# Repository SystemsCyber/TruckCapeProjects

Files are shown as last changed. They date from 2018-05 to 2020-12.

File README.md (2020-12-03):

# TruckCapeProjects
Projects teaching the basics of using the TruckDuck or Truck Cape on a Beagle Bone Black with Python.

Checkout the Jupyter directory for Python code embedded in a Juptyer notebook. To start a jupyter server on the Beagle Bone, use this command:

```
jupyter notebook --ip 192.168.7.2 --no-browser
```

Note: this is not secure, so only use this on a local network or USB connection.

## Getting Started
Login to your beaglebone and run the following command to copy this repository into your directory:

```
git clone https://github.com/SystemsCyber/TruckCapeProjects.git
```

Once this is copied in, you can update the repository by changing directory into the repostory and running ```git pull```

## Hardware
See the docs directory for details. You can buy the board directly from OSHPark and source the parts from Digikey or Mouser. 

## Linux
The Linux image to run on the BeagleBone's eMMC can be downloaded, decompressed, imaged to an SD card. When the BeagleBone Black boots from the SD card, it will burn the eMMC to have the necessary contents to run the exercises in this repository. 

For the impatient, here is a link to the most current image based on the modifications:

[TruckCapeImage-2020-11-14_4.19.img.xz](https://www.engr.colostate.edu/~jdaily/files/TruckCapeImage-2020-11-14_4.19.img.xz)

This image was built based on the guidance in [OSBuildInstructions.md](OSBuildInstructions.md).

## Getting Started
### Windows Software
If this is your first time with a Heavy Truck Cape with BeagleBoneBlack, then you'll need some software on your computer to interface with it. This readme assumes you are using Windows. Linux and Mac have shell utilities built-in already. For Windows users, you'll need the following:
1. PuTTy
2. WinSCP 

### Logging In
1. Plug in the a Mini USB cable between the BeagleBone and your computer
2. Give the system some time to boot
2. Open PuTTy
3. Specify the Host Name (or IP address) as 192.168.7.2
4. Press Open
5. Use the following credentials:

Default Credentials
U: debian P: temppwd
Please change the password if this is connected to the Internet.

### Logging Out or Shutting Down
The system may shut down if the +12V feed is removed, even if the USB or 5V power jack is connected. Be sure to shut down the Linux system before unplugging the device. 

```
sudo shutdown -h now
```

### Change the Baud Rate
To figure out the bitrate of the devices, issue the following command
```
ip -details -statistics link show can1
```
which gives output like the following showing a bitrate of 250000 bps.
```
can1: <NOARP,UP,LOWER_UP,ECHO> mtu 16 qdisc pfifo_fast state UNKNOWN mode DEFAULT qlen 10
    link/can
    can state ERROR-PASSIVE (berr-counter tx 0 rx 127) restart-ms 0
    bitrate 250000 sample-point 0.875
    tq 250 prop-seg 6 phase-seg1 7 phase-seg2 2 sjw 1
    c_can: tseg1 2..16 tseg2 1..8 sjw 1..4 brp 1..1024 brp-inc 1
    clock 24000000
    re-started bus-errors arbit-lost error-warn error-pass bus-off
    0          0          0          123        25203      0
    RX: bytes  packets  errors  dropped overrun mcast
    2611059    336058   0       0       0       0
    TX: bytes  packets  errors  dropped carrier collsns
    0          0        0       0       0       0
```

Enter the following commmands to change the CAN bitrate to 666000 on the CAN0 channel.
CAN0 on SocketCAN is the CAN2 channel on the J1939 connector.
```
sudo ip link set can0 down
sudo ip link set can0 type can bitrate 666666
sudo ip link set can0 up
```
The resulting terminal should display something like this if CAN0 is connected to a 666k CAN network.
```
candump can0
  can0  10EBFF3D   [8]  01 00 00 00 00 00 00 00
  can0  10EBFF3D   [8]  01 00 00 00 00 00 00 00
  can0  10EBFF3D   [8]  01 00 00 00 00 00 00 00
  can0  08FE6E0B   [8]  FF FF FF FF FF FF FF FF
  can0  14FEAE17   [8]  FF FF FF FF FF FF FF FF
  can0  08FF0400   [8]  01 00 00 00 A8 61 4D 12
  can0  08FF0400   [8]  01 00 00 00 A8 61 6D 76
  can0  10EBFF3D   [8]  01 00 00 00 00 00 00 00
  can0  08FF0400   [8]  01 00 00 00 A8 61 4D 12
```

A similar strategy will be used for CAN1 and other bit rates.

## Challenge Ideas
### Log all data to an SD Card
Adapt the startup script to log all data from the J1939 (CAN1), CAN0, and Both J1708 channels to log to files on a large SD card installed in the BeagleBone card slot.

### Automatic RTC
Add the ability to set the time using the an I2C based Real Time Clock chip. Normal operation relies on a network connection to get time.

### Send and Receive CAN messages over UDP
Build a network bridge for CAN and Ethernet. 

### Build a can-utils website
Host a website on the Beaglebone to interface with SocketCAN

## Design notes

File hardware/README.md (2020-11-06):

# TruckCape for the Beagle Bone Black

This directory has Altium schematics, printed circuit boards, and PCB project files.

All components are through hole, so it is easy to build with just a soldering iron.

PDFs of the schematics are available. The board in this design is available for version 3 as an OSHPark shared project: https://oshpark.com/shared_projects/FXh7K628

## Errata
The rev 4 board calls for a B82134 Inductor, but that component is too big. Instead, use a B82131 Inductor. The Bill of Materials for v4 accurately reflects this change. 

The bottom silkscreen on the v4 PCB is mislabeled. It should match the schematic and have only 1 common supply (COM) and 4 open collector outputs (low-side switches).

PWM2 and PWM4 signals went to non-PWM pins. These pins were also loaded because the Darlington Array (ULQ2003AN) has a path to ground through the base. Therefore, the BBB won't boot when pins 43 and 44 are driven. These pins need to be cut.

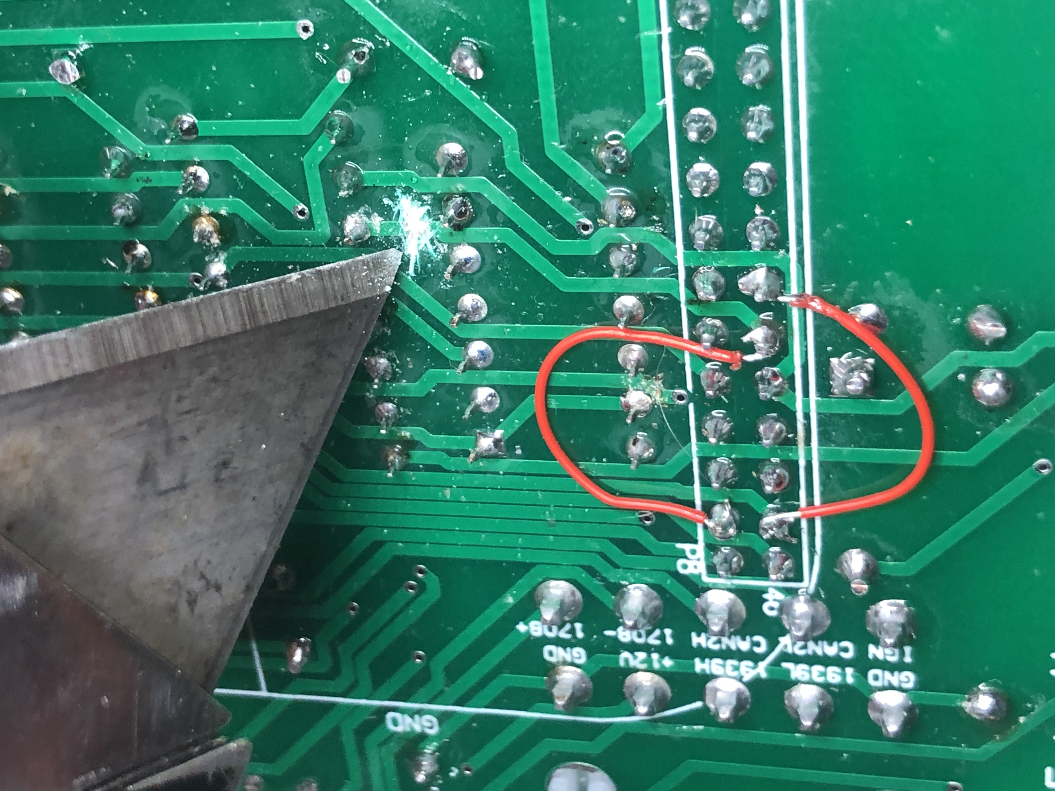
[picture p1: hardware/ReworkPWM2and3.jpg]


The new pins for PWM2 and PWM3 are P8.34 and P8.36, respectively. However, the PWM6_OUT was tied to P8.36. This signal line needs to be cut. PWM6_OUT also has R11 pulling the signal high. Since this is now an output for PWM3, the pullup resistor needs to be removed. Be sure R11 is not populated.

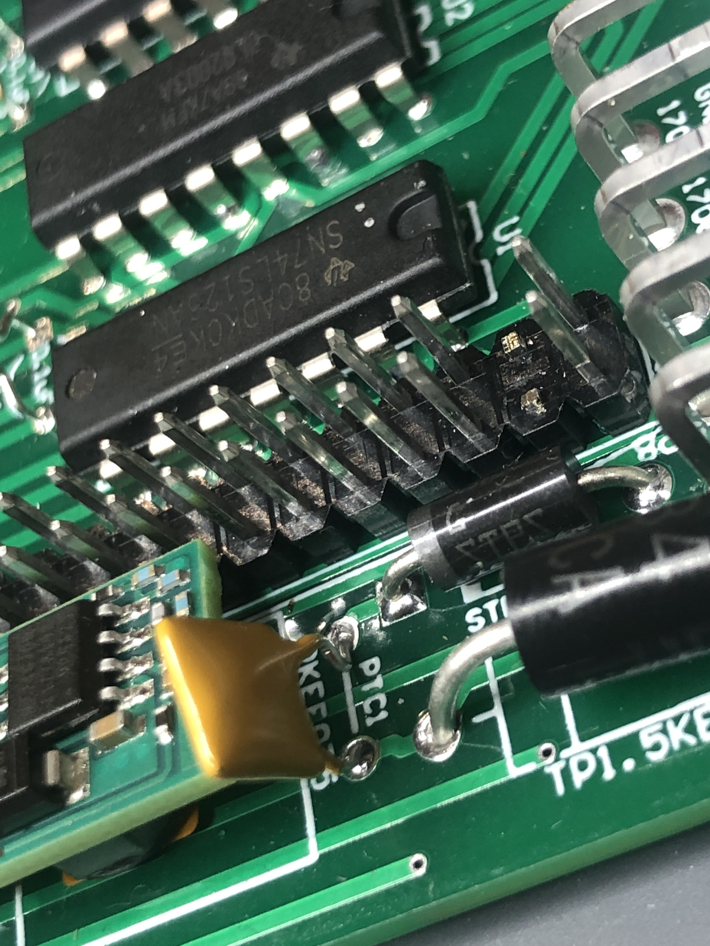
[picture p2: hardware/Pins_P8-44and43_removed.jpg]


The handannotated schematic is available TruckCape v4 Schematic Modified.pdf

## External Cable Connections
The board cutout can accomodate a 10-pin Molex Mini-Fit Jr connector to break out the J1939 connector. The cable for this is specified with the Cable Drawing.

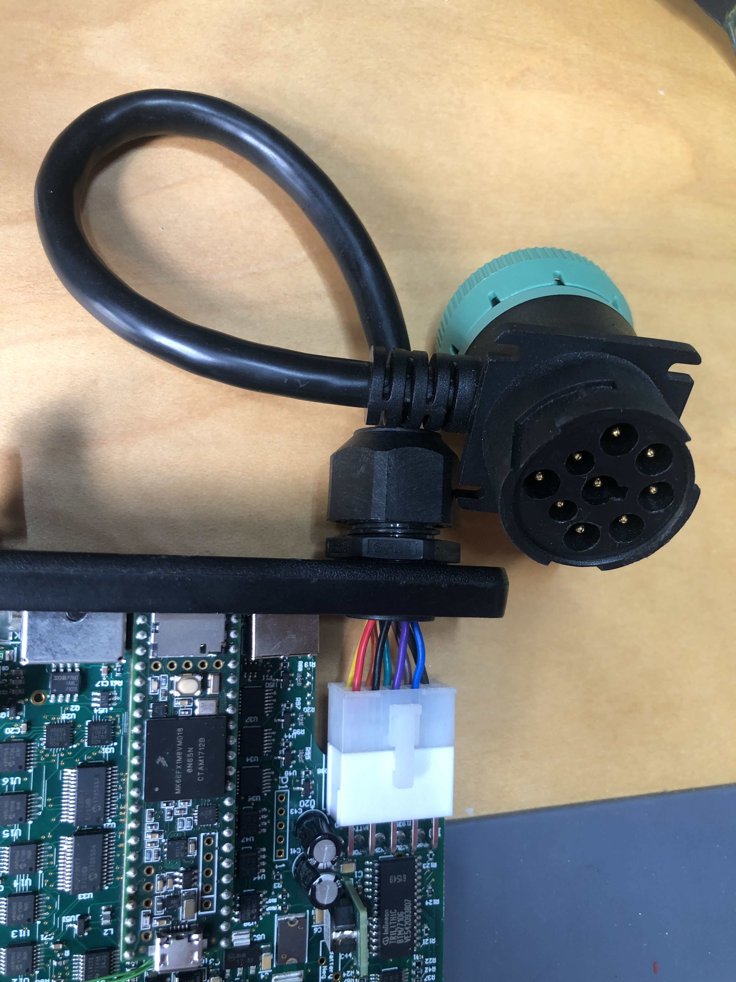
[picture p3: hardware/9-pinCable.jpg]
Cable in Cord Grip


To assemble this component, follow these steps:
1. Cut a hole in the side panel to fit a cord grip.
1. Insert the cable through the cord grip.
1. Tighten the cord grip in the side panel with the hole. Don't tighten the grip around the cable yet.
2. insert the wires into the Molex 10 pin connector (part number 39-01-2100 from https://www.digikey.com/product-detail/en/molex/0039012100/WM3704-ND/61385) according to the following table:

| Signal | Deutsch 9-pin Label | Color | Molex Cavity |
| --- | --- | --- | --- |
| Ground | A | Yellow | 1 |
| Power | B | Orange | 2 |
| J1939 H | C | Green | 3 |
| J1939L | D | Brown | 4 |
| Shield | E | Bare (Blk) | 5 |
| J1708H | F | Red | 6 |
| J1708L | G | Black | 7 |
| CAN2H	 | H | Purple | 8 |
| CAN2L	 | J | Blue | 9 |

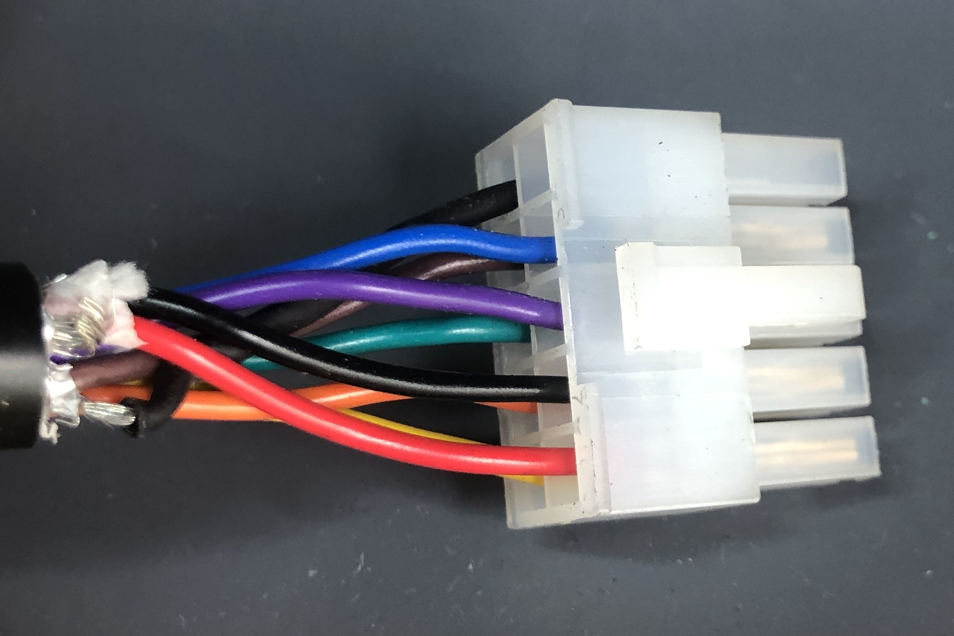
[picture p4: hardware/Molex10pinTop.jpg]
Top Side


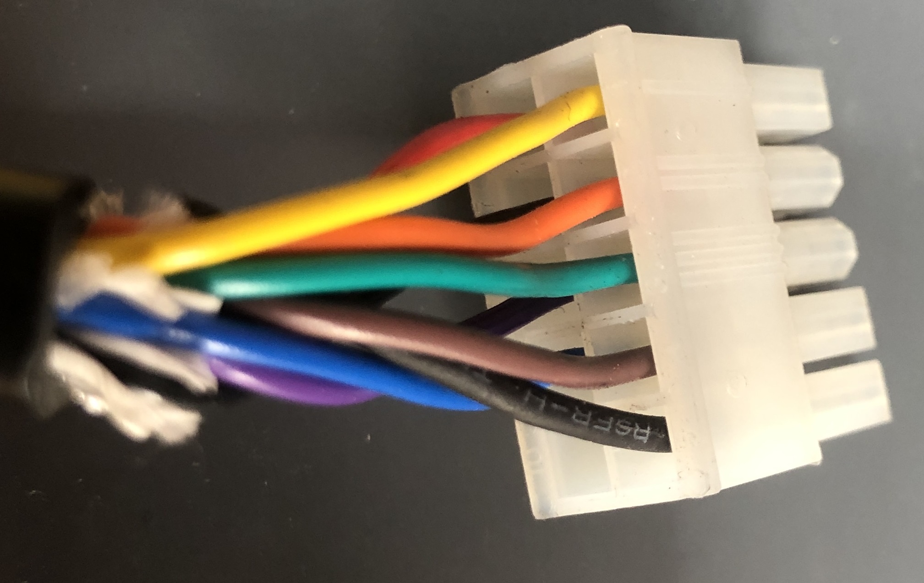
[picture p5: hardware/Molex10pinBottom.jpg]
Bottom Side


### Trace Routing and Enclosure Issues
There are traces under the solder mask that coincide with the aluminum rails. This is not a short-term issue, but if the mask is scratched, it could short to the aluminum enclosure. Perhaps a layer of kapton tape could improve the reliability. 

### Testing PWM pins on v4
The following commands will turn on PWM signals:
```
debian@beaglebone:~$ python3
Python 3.7.3 (default, Dec 20 2019, 18:57:59) 
[GCC 8.3.0] on linux
Type "help", "copyright", "credits" or "license" for more information.
>>> import Adafruit_BBIO.PWM as PWM
>>> PWM.start("P8_34",1,5)
>>> PWM.start("P8_36",10,5)
>>> PWM.start("P8_46",20,2)
>>> PWM.start("P8_45",80,2)
```
Each PWM channel needs to have the same frequency.

Pins 34 and 36 comprise channel 1.

Pins 45 and 46 comprise channel 2.

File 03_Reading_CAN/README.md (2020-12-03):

# Notes for read_CAN.py

This solution should demonstrate the way raw controller area network data is read from SocketCAN.

If you don't have a truck network to connect to, run this command to see network traffic virtually:
```canplayer -l i -I candump_kw_drive.txt vcan0=can1 &```

The challenge is to setup the correct struct format string to properly read the data from the SocketCAN interface. 
See https://docs.python.org/3/library/struct.html for help with the interpretation string.

Once your program is successful, the output may look something like this:

```debian@beaglebone:~/TruckCapeProjects/03_Reading_CAN/solution$ python3 read_CAN.py 
vcan0 18FEF200 [8] 8C 00 00 00 0D 06 0D FF
vcan0 18FEF500 [8] C4 FF FF 26 25 FF FF FF
vcan0 18FEC100 [8] 52 C5 3C 09 FF FF FF FF
vcan0 18FEE000 [8] FF FF FF FF 40 97 5E 00
vcan0 18FEBD00 [8] FF F0 00 00 FF FF FF FF
vcan0 18FEE400 [8] F0 FF FF FC F0 FF FF FF
vcan0 18FEF700 [8] FF FF FF FF 20 01 FF FF
vcan0 18FD7C00 [8] F8 F3 F3 FF FF FF E3 FF
vcan0 18EA3100 [3] E6 FE 00
vcan0 1CECFF0F [8] 20 13 00 03 FF E1 FE 00
vcan0 0CF00400 [8] 50 89 91 2C 15 00 F0 FF
vcan0 0CF00400 [8] 30 89 8F 2C 15 00 F0 FF
vcan0 08FE6E0B [8] E0 01 A0 01 A0 01 60 01
```

## Troubleshooting

### No such device
Symptom: 
You get this error when running ```python3 read_CAN.py```:

```
Traceback (most recent call last):
  File "read_CAN.py", line 20, in <module>
    sock.bind((interface,))
OSError: [Errno 19] No such device
```

Solution: You need to set the interface using the virtual can interface (vcan).

### No data is playing
Symptom: After running ```python3 read_CAN.py``` there is nothing happening in the terminal.

Solution: Use canplayer to send messages to the virtual CAN device. You'll need to download a CAN log to work with, like the one in this repository. For more logs, you can find information at https://www.engr.colostate.edu/~jdaily/J1939/candata.html.

Use the following command to run the canplayer in the background in an infinite loop:

```canplayer -l i -I candump_kw_drive.txt vcan0=can1 &```

## Setting up vcan0
Follow instructions at https://www.kernel.org/doc/html/latest/networking/can.html#the-virtual-can-driver-vcan

To setup a virtual can interface, do the following:
```sudo ip link add type vcan```

Turn on the vcan interface:
```sudo ip link set vcan0 up```

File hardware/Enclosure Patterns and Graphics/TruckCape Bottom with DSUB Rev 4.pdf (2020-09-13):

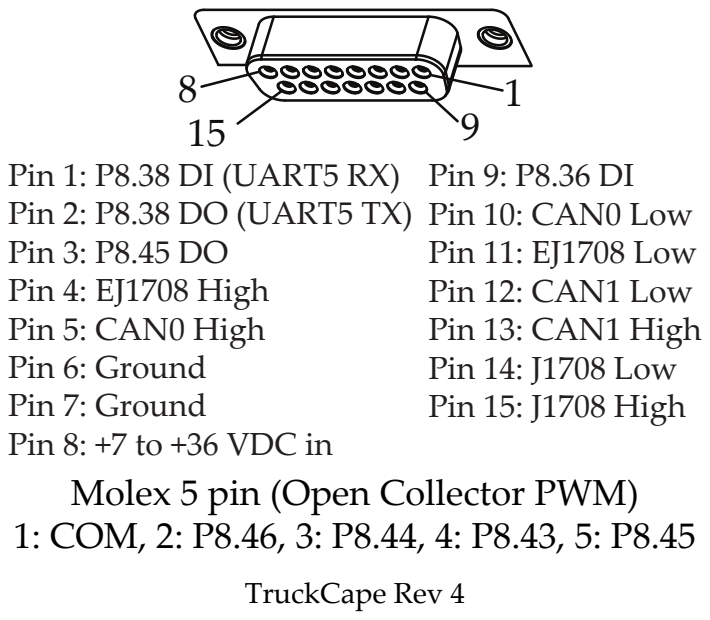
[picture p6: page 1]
Pin 9: P8.36 DI Pin 10: CAN0 Low; Pin 12: CAN1 Low Pin 13: CAN1 High Pin 14: J1708 Low Pin 15: J1708 High; Pin 11: EJ1708 Low; TruckCape Rev 4

Pin 1: P8.38 DI (UART5 RX)
Pin 2: P8.38 DO (UART5 TX)
Pin 3: P8.45 DO
Pin 4: EJ1708 High
Pin 5: CAN0 High
Pin 6: Ground
Pin 7: Ground
Pin 8: +7 to +36 VDC in
Molex 5 pin (Open Collector PWM)
1: COM, 2: P8.46, 3: P8.44, 4: P8.43, 5: P8.45

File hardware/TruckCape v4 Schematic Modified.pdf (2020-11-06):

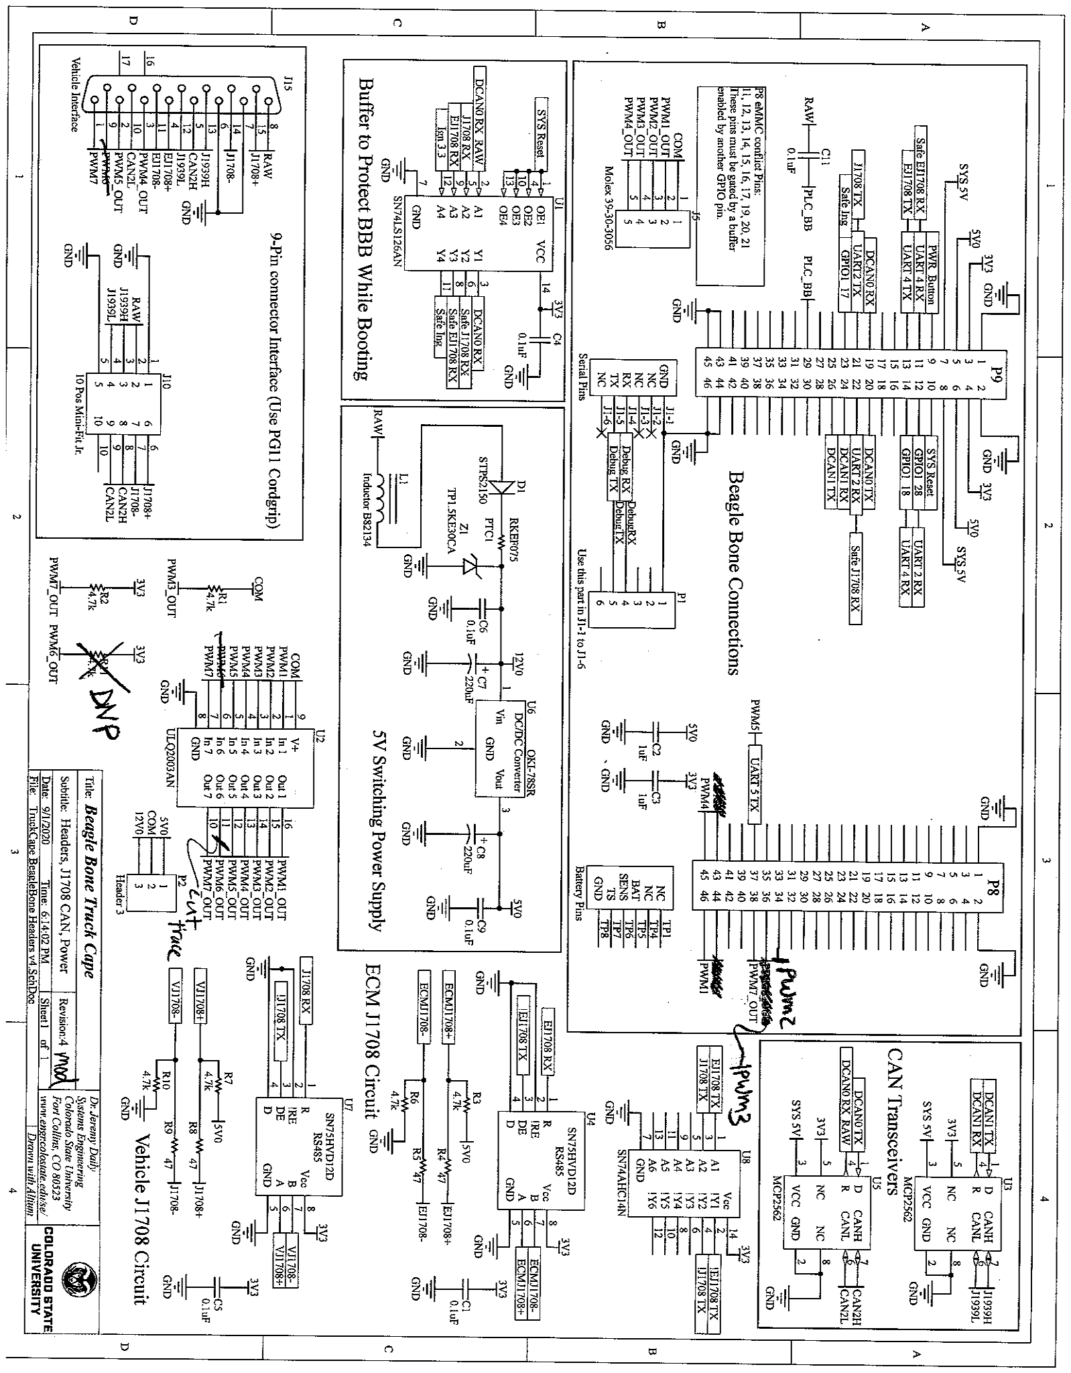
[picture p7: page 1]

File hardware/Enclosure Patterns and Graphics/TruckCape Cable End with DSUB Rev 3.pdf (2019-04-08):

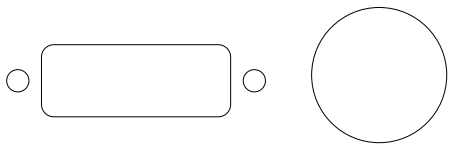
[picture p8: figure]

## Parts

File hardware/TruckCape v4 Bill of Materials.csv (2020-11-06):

Comment | Description | Designator | Footprint | Quantity | Manufacturer | PartNumber | Supplier 1 | Supplier Part Number 1
BBone Headers | 46 Positions Header, Breakaway Connector 0.100 (2.54mm) Through Hole Tin" | BeagleBoneBlack1 | Beagleboneblack | 2 | Sullins Connector Solutions | PREC023DAAN-RC | Digi-Key | S2012EC-23-ND
0.1uF | CAP CER 0.1UF 100V X7R RADIAL | C1, C4, C5, C6, C9, C11 | CAPR5-4X5 | 6 | Vishay BC Components | K104K20X7RH53H5 | Digi-Key | BC5139-ND
1uF | CAP CER 1UF 100V X7R RADIAL | C2, C3 | CAPR5-4X5 | 2 | Murata Electronics North America | RDER72A105K2M1H03A | Digi-Key | 490-9198-1-ND
220uF | 220µF 50V Aluminum Electrolytic Capacitors Radial, Can 175 mOhm @ 10kHz 5000 Hrs @ 105°C | C7, C8 | Elec. Cap 5 x 10mm | 2 | EPCOS (TDK) | B41858C6227M000 | Digi-Key | 495-6000-ND
STPS2150 | Diode Schottky 150V 2A Through Hole DO-15 | D1 | DO-41 | 1 | STMicroelectronics | STPS2150 | Digi-Key | 497-3213-1-ND
Molex 39-30-3056 | 5 Positions Header Connector 0.165 (4.20mm) Through Hole - Right Angle Tin" | J5 | 5 POS MINI-FIT JR R/A Header | 1 | Molex | 39-30-3055 | Digi-Key | WM18448-ND
10 Pos Mini-Fit Jr. | 10 Positions Header Connector 0.165 (4.20mm) Through Hole - Right Angle Tin" | J10 | 10 pos Mini-Fit Jr. R/A Header | 1 | Molex | 39-30-1100 | Digi-Key | WM1355-ND
Vehicle Interface | Receptacle Assembly, 15 Position, Right Angle, 8.08mm Series, Amplimite, with Screwlocks | J15 | DB15 | 1 | Amphenol FCI | D15S33E4GX00LF | Digi-Key | 609-1499-ND
Inductor B82131 | 14µH Unshielded Wirewound Inductor 700mA 760mOhm Axial | L1 | AXIAL-0.9 | 1 | TDK Electronics Inc. | B82131A5701M000 | Digi-Key | 495-5602-1-ND
Use this part in J1-1 to J1-6 | CONN HEADER FEMALE 6POS .1 GOLD" | P1 | HDR1X6 | 1 | Sullins Connector Solutions | PPPC061LFBN-RC | Digi-Key | S7039-ND
Shunt Switch | 2 (1 x 2) Position Shunt Connector Black Open Top 0.100 (2.54mm) Gold" | P2 Shunt |  | 1 | Sullins Connector Solutions | QPC02SXGN-RC | Digi-Key | S9337-ND
RKEF075 | Polymeric PTC Resettable Fuse 60V 750mA Ih Through Hole Radial, Disc | PTC1 | PTC | 1 | Littelfuse Inc. | RKEF075 | Digi-Key | RKEF075HF-ND
4.7k | RES SMD 4.7K OHM 1% 1/10W 0603 | R1, R2, R3, R6, R7, R10 | Axial-0.4 | 6 | Yageo | CFR-25JB-52-4K7 | Digi-Key | 4.7KQBK-ND
47 | 47 Ohms ±5% 0.25W, 1/4W Through Hole Resistor Axial Carbon Film | R4, R5, R8, R9 | Axial-0.4 | 4 | Yageo | CFR-25JB-52-47R | Digi-Key | 47QBK-ND
SN74LS126AN | Quad 3-State Buffer | U1 | N14A | 1 | Texas Instruments | SN74LS126AN | Digi-Key | 296-3643-5-ND
ULQ2003AN | High voltage, high current Darlington arrays each containing seven open collector Darlington pairswith common emitters. | U2 | DIP16 | 1 | Texas Instruments | ULQ2003AN | Digi-Key | 296-22623-5-ND
MCP2562 | 1/1 Transceiver Half CAN 8-PDIP | U3, U5 | PDIP300-P8 | 2 | Microchip Technology | MCP2562-E/P | Digi-Key | MCP2562-E/P-ND
SN75HVD12 | IC 3.3V DIFF TXRX 8-SOIC | U4, U7 | PDIP300-P8 | 2 | Texas Instruments | SN75HVD12P | Digi-Key | 296-14047-5-ND
OKI-78SR | 5V DC/DC Converter (7805 replacement) | U6 | OKI-78SR | 1 | Murata Power Solutions Inc. | OKI-78SR-5/1.5-W36H-C | Digi-Key | 811-2692-ND
SN74AHC14N | Inverter IC 6 Channel Schmitt Trigger 14-PDIP | U8 | N14A | 1 | Texas Instruments | SN74AHC14N | Digi-Key | 296-4550-5-ND
TP1.5KE30CA | TVS DIODE 25.6V 41.4V DO201 | Z1 | DIODE-0.7 | 1 | Littelfuse Inc. | TP1.5KE30CA | Digi-Key | F7610CT-ND
Debug Port | CONN HEADER VERT 6POS 2.54MM | Debug | HDR1X6 | 1 | Sullins Connector Solutions | PBC06SFAN | Digi-Key | S1211E-06-ND
BeagleBone Black | BEAGLEBONE BLK REV C AM3358BZCZ | BBB | Beagleboneblack | 1 | GHI Electronics, LLC | BBB01-SC-505 | Digi-Key | BBB01-SC-505-ND
Enclosure | BOX ALUM BLACK 4.72"L X 3.07"W | Encl |  | 1 | Hammond Manufacturing | 1455K1202BK | Digi-Key | HM1724-ND
COM Switch Header | CONN HEADER VERT 3POS 2.54MM | P2 | HDR1X3 | 1 | Sullins Connector Solutions | PBC03SFAN | Digi-Key | S1211E-03-ND
Cord Grip | CABLE GLAND 5-7.5MM PG11 NYLON | CG1 |  | 1 | Bud Industries | NG-9513 | Digi-Key | 377-1923-ND
Screws | JACK SCREW HEX 4-40 1=2 | J15-Screws |  | 1 | Keystone Electronics | 7230-5 | Digi-Key | 36-7230-5-ND
Cable | KL68-04 Deutsch 9Pin dual-headed to molex terminals | Cable1 |  | 1 | Cactus Electronics | KL68-04 | Cactus Electronics | KL68-04
P10 | CONN RECEPT 10POS DUAL | P10 |  | 1 | Molex | 39-01-2100 | Digi-Key | WM3704-ND

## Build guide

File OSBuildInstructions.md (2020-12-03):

# Installing the Linux Operating System.

These steps were taken to build the TruckCape recovery SD card. If you have a truck-cape from 2020, then these steps have already been done.

1. Download 

https://debian.beagleboard.org/images/bone-eMMC-flasher-debian-10.3-iot-armhf-2020-04-06-4gb.img.xz

1. Using a utility like 7zip, decompress the image.

1. Using Win32DiskImager, burn the Debian Linux distribution to a 4GB SD partition. This will be a flasher image that will overwrite the eMMC chip in the BeagleBone Black.

1. Insert the flasher image SD card into to the BeagleBone Black. Power on the BBB (i.e. plug in the USB) while depressing the SD boot button until the 4 user LEDs come on. After about 30 seconds, the flasher program will start as indicated by the user leds cycling in a back-and-forth pattern. The reflashing process could take 10-15 minutes, depending on the speed of the SD card. 

## Testing the System
Using an SSH client, like PuTTYy, and a USB to computer connection, connect to the Beagle Bone Black SSH using IP 192.168.7.2 on port 22.

The new login uses the following credentials:

U: debian

P: temppwd

The availability if this connection may take longer than you might like, but be patient, the board will finish booting and enumerate as a drive on your host computer. 

Connect a live Internet connection by the Ethernet cable into your Beagle Bone Black. Check to see if you have a valid IP address on `eth0`:

```
sudo ifconfig
```

### What Version do you have?
If you are having troubles, be sure you are using the same version that's documented here. When the kernel changes, the results may be different. 

Enter the following command `cat /etc/dogtag`:

```
debian@beaglebone:~$ cat /etc/dogtag
BeagleBoard.org Debian Buster IoT Image 2020-04-06
```

Check the kernel version:

```
debian@beaglebone:~$ uname -a
Linux beaglebone 4.19.94-ti-r42 #1buster SMP PREEMPT Tue Mar 31 19:38:29 UTC 2020 armv7l GNU/Linux
```

## Pin Multiplexing Setup for CAN and Others

References:

https://www.beyondlogic.org/adding-can-to-the-beaglebone-black/

https://www.bacpeters.com/2020/01/25/configuring-the-beaglebone-black-gpio-pins-permanently/

### Disable Unused Hardware
Edit the uEnv.txt file and uncomment the some disable commands. This opens the pins up for accessing other functions.

```
sudo nano /boot/uEnv.txt
```
Uncommment the disable_uboot_overlay as follows:
```
#dtb_overlay=/lib/firmware/<file8>.dtbo
###
###Disable auto loading of virtual capes (emmc/video/wireless/adc)
#disable_uboot_overlay_emmc=1
disable_uboot_overlay_video=1
disable_uboot_overlay_audio=1
disable_uboot_overlay_wireless=1
disable_uboot_overlay_adc=1
###
```
Be sure to keep the emmc line commented, since that's the root file system.

Also, enable the universal overlay. This ensures the kernel has access to the hardware pin multiplexers. 

```
###Additional custom capes
uboot_overlay_addr4=/lib/firmware/cape-universal.dtbo
#uboot_overlay_addr5=/lib/firmware/<file5>.dtbo
#uboot_overlay_addr6=/lib/firmware/<file6>.dtbo
#uboot_overlay_addr7=/lib/firmware/<file7>.dtbo
###

```

Finally, enable uio_pruss kernel module for the Programmable Realtime Unit (PRU).
```
###PRUSS OPTIONS
###pru_rproc (4.14.x-ti kernel)
#uboot_overlay_pru=/lib/firmware/AM335X-PRU-RPROC-4-14-TI-00A0.dtbo
###pru_rproc (4.19.x-ti kernel)
#uboot_overlay_pru=/lib/firmware/AM335X-PRU-RPROC-4-19-TI-00A0.dtbo
###pru_uio (4.14.x-ti, 4.19.x-ti & mainline/bone kernel)
uboot_overlay_pru=/lib/firmware/AM335X-PRU-UIO-00A0.dtbo
###
```

Save and reboot: `sudo shutdown -r now`

Verify the uio_pruss kernel module is running:
```
lsmod | grep pru
```

### Configure the pins
Write the following commands to get the CAN hardware to access the pins upon boot. 
Create a file in the /etc directory:

```
sudo nano /etc/pin_config.sh
```
Write the following into the directory:
```
#!/bin/sh -e
# DCAN1
config-pin p9.24 can
config-pin p9.26 can 
# DCAN0
config-pin p9.19 can
config-pin p9.20 can
#ttyO2:
config-pin p9.21 uart
config-pin p9.22 uart
#ttyO4:
config-pin p9.11 uart
config-pin p9.13 uart
#ttyO5:
config-pin p8.37 uart
config-pin p8.38 uart
# PWMs
config-pin p8.46 pwm
config-pin p8.45 pwm
config-pin p8.34 pwm
config-pin p8.36 pwm
# GPIO
config-pin p9.12 gpio
config-pin p9.14 gpio

exit 0
```
Make the script executable:
```
sudo chmod +x /etc/pin_config.sh
```
However, these commands need to be run upon boot, so let's make a script to do this and add it to a boot sequence.

```
sudo nano /lib/systemd/system/pin_config.service
```
Add this to the file:
```
[Unit]
Description=Setup for BBB

[Service]
Type=simple
ExecStart=/bin/bash /etc/pin_config.sh

[Install]
WantedBy=multi-user.target
```

Start the service

```
sudo systemctl start pin_config.service
```

Verify the service

```
sudo systemctl status pin_config.service
```
Enable the service at boot

```
sudo systemctl enable pin_config.service
```
To confirm the pin_config.service was enabled, look for a symbolic link in `/etc/systemd/system`

```
debian@beaglebone:/etc/systemd/system$ ls -la
lrwxrwxrwx  1 root root   38 Sep 17 04:51 pin_config.service -> /lib/systemd/system/pin_config.service
```

Reboot and verify. `sudo shutdown -r now`

```
debian@beaglebone:~$ config-pin -q p9.24

Current mode for P9_24 is:     can

```

Verify the status of the pin_config.service was successful by looking for an output like this:

```
debian@beaglebone:~$ sudo systemctl status pin_config.service
● pin_config.service - Setup for BBB p
   Loaded: loaded (/etc/systemd/system/pin_config.service; enabled; vendor preset: enabled)
   Active: inactive (dead) since Tue 2020-09-08 23:52:06 UTC; 2min 18s ago
  Process: 856 ExecStart=/bin/bash /home/debian/pin_config.sh (code=exited, status=0/SUCCESS)
 Main PID: 856 (code=exited, status=0/SUCCESS)

Sep 21 14:06:18 beaglebone bash[2040]: Current mode for P9_13 is:     uart
Sep 21 14:06:18 beaglebone bash[2040]: Current mode for P8_37 is:     uart
Sep 21 14:06:18 beaglebone bash[2040]: Current mode for P8_38 is:     uart
Sep 21 14:06:18 beaglebone bash[2040]: Current mode for P8_46 is:     pwm
Sep 21 14:06:18 beaglebone bash[2040]: Current mode for P8_45 is:     pwm
Sep 21 14:06:18 beaglebone bash[2040]: Current mode for P8_34 is:     pwm
Sep 21 14:06:18 beaglebone bash[2040]: Current mode for P8_36 is:     pwm
Sep 21 14:06:18 beaglebone bash[2040]: Current mode for P9_12 is:     gpio
Sep 21 14:06:18 beaglebone bash[2040]: Current mode for P9_14 is:     gpio
Sep 21 14:06:18 beaglebone systemd[1]: pin_config.service: Succeeded.
```
If this doesn't work, be sure to disable the overlays in the uEnv.txt file.

### Start the network interfaces
Edit your `/etc/network/interfaces` file.

```
sudo nano /etc/network/interfaces
```

Add the following lines:

```
allow-hotplug can1
 iface can1 can static
    bitrate 250000

allow-hotplug can0
 iface can0 can static
    bitrate 250000
```
Reboot: `sudo shutdown -r now`

Upon restart, the CAN interfaces should be mounted.

```
debian@beaglebone:~$ sudo ifconfig
[sudo] password for debian:
can0: flags=193<UP,RUNNING,NOARP>  mtu 16
        unspec 00-00-00-00-00-00-00-00-00-00-00-00-00-00-00-00  txqueuelen 10  (UNSPEC)
        RX packets 19375  bytes 155000 (151.3 KiB)
        RX errors 0  dropped 0  overruns 0  frame 0
        TX packets 0  bytes 0 (0.0 B)
        TX errors 0  dropped 0 overruns 0  carrier 0  collisions 0
        device interrupt 42

can1: flags=193<UP,RUNNING,NOARP>  mtu 16
        unspec 00-00-00-00-00-00-00-00-00-00-00-00-00-00-00-00  txqueuelen 10  (UNSPEC)
        RX packets 50893  bytes 407139 (397.5 KiB)
        RX errors 0  dropped 0  overruns 0  frame 0
        TX packets 0  bytes 0 (0.0 B)
        TX errors 0  dropped 0 overruns 0  carrier 0  collisions 0
        device interrupt 43

eth0: flags=-28669<UP,BROADCAST,MULTICAST,DYNAMIC>  mtu 1500
        ether ec:24:b8:72:7d:ef  txqueuelen 1000  (Ethernet)
        RX packets 0  bytes 0 (0.0 B)
        RX errors 0  dropped 0  overruns 0  frame 0
        TX packets 0  bytes 0 (0.0 B)
        TX errors 0  dropped 0 overruns 0  carrier 0  collisions 0
        device interrupt 55

lo: flags=73<UP,LOOPBACK,RUNNING>  mtu 65536
        inet 127.0.0.1  netmask 255.0.0.0
        inet6 ::1  prefixlen 128  scopeid 0x10<host>
        loop  txqueuelen 1000  (Local Loopback)
        RX packets 400  bytes 27920 (27.2 KiB)
        RX errors 0  dropped 0  overruns 0  frame 0
        TX packets 400  bytes 27920 (27.2 KiB)
        TX errors 0  dropped 0 overruns 0  carrier 0  collisions 0

usb0: flags=4163<UP,BROADCAST,RUNNING,MULTICAST>  mtu 1500
        inet 192.168.7.2  netmask 255.255.255.0  broadcast 192.168.7.255
        inet6 fe80::ee24:b8ff:fe72:7df1  prefixlen 64  scopeid 0x20<link>
        ether ec:24:b8:72:7d:f1  txqueuelen 1000  (Ethernet)
        RX packets 1895  bytes 136356 (133.1 KiB)
        RX errors 0  dropped 4  overruns 0  frame 0
        TX packets 2105  bytes 472901 (461.8 KiB)
        TX errors 0  dropped 0 overruns 0  carrier 0  collisions 0

usb1: flags=4099<UP,BROADCAST,MULTICAST>  mtu 1500
        inet 192.168.6.2  netmask 255.255.255.0  broadcast 192.168.6.255
        ether ec:24:b8:72:7d:f5  txqueuelen 1000  (Ethernet)
        RX packets 0  bytes 0 (0.0 B)
        RX errors 0  dropped 0  overruns 0  frame 0
        TX packets 0  bytes 0 (0.0 B)
        TX errors 0  dropped 0 overruns 0  carrier 0  collisions 0
```
If there is a live CAN bus connected, try `candump any` and confirm message traffic.

```
debian@beaglebone:~$ candump any
  can0  0CFEF100   [8]  FB FF FE AA AA 00 1F FF
  can1  08FE6E0B   [8]  FF FE FF FE FF FE FF FE
  can1  0CF00400   [8]  00 7D 7D 00 00 00 F0 7D
  can0  0CF00400   [8]  00 7D 7D 00 00 00 F0 7D
  can1  18F00E00   [8]  A0 0F FE 71 FF FF FF FF
  can0  18E0FF00   [8]  00 FF FF FF FF FA FF FF
  can1  18FEF200   [8]  00 00 FF FE BF 05 FE FF
  can1  18FEDF00   [8]  86 FF FF FF 7D FF FE 00
  can1  0CF00400   [8]  00 7D 7D 00 00 00 F0 7D
  can0  0CF00400   [8]  00 7D 7D 00 00 00 F0 7D
  can0  18F0000F   [8]  20 7D 7D F3 00 7D FE 63
  can1  10FDA300   [8]  FF FF FA FF FF FF FF FF
  can1  18FEE000   [8]  FF FF FF FF 0F 14 0A 00
  can1  18FD0900   [8]  FF FF FF FF 0C 78 B6 01
  can1  08FE6E0B   [8]  FF FE FF FE FF FE FF FE
  can1  1CEBFF00   [8]  0C 01 7F 02 09 01 84 06
  can0  0CF00400   [8]  00 7D 7D 00 00 00 F0 7D
  can1  0CF00400   [8]  00 7D 7D 00 00 00 F0 7D
  can0  18FEF200   [8]  00 00 FF FE BF 05 FE FF
  can1  18FF4500   [8]  78 2A FA 00 FF 00 00 AC
  can1  18FEDF00   [8]  86 FF FF FF 7D FF FE 00
  can1  1CFE9200   [8]  FF 80 97 FF FF FF FF FF
  can1  18F0010B   [8]  CC FF F0 FF FF 5C FF FF
  can1  0CF00400   [8]  00 7D 7D 00 00 00 F0 7D
  can0  0CF00400   [8]  00 7D 7D 00 00 00 F0 7D
  can1  0CF00300   [8]  FA FE 00 FF FF 0C 00 FF
  can0  18FEE000   [8]  FF FF FF FF 0F 14 0A 00
  can1  18FEEF00   [8]  FE FF FF FE FF FF FF 00
  can1  18FF4800   [8]  00 00 F3 FF 00 00 00 00
  can1  18FEE0CA   [8]  FF FF FF FF FF FF FF FF
  can1  18FEBF0B   [8]  FF FE FE FE FE FE FF FF
  can1  08FE6E0B   [8]  FF FE FF FE FF FE FF FE
  can1  0CF00400   [8]  00 7D 7D 00 00 00 F0 7D
```
### Add virtual CAN drivers
The vcan interfaces are great ways to develop hardware without needing to troubleshoot physical CAN connections or have access to a truck.

Write a script to stand up some vcan devices. 
```
sudo nano /etc/network/vcan-start.sh
```
Enter these commands into the file:
```
#!/bin/sh -e
ip link add type vcan 
ip link set vcan0 up
ip link add dev vcan1 type vcan
ip link set vcan1 up
ip link add dev vcan2 type vcan
ip link set vcan2 up
exit 0
```

Make the script executable:
```
sudo chmod +x /etc/network/vcan-start.sh
```
This script should be run upon boot, so let's make a script to do this and add it to a boot sequence.

```
sudo nano /lib/systemd/system/vcan.service
```
Add this to the file:
```
[Unit]
Description=Turn on virtual CAN interfaces

[Service]
Type=simple
ExecStart=/bin/bash /etc/network/vcan-start.sh

[Install]
WantedBy=multi-user.target
```

Start the service

```
sudo systemctl start vcan.service
```

Verify the service

```
sudo systemctl status vcan.service
```
Enable the service at boot

```
sudo systemctl enable vcan.service
```
To confirm the pin_config.service was enabled, look for a symbolic link in `/etc/systemd/system`

```
ls -la /etc/systemd/system/multi-user.target.wants/
lrwxrwxrwx  1 root root   32 Nov  7 15:27 vcan.service -> /lib/systemd/system/vcan.service
```
should show a line
```
lrwxrwxrwx  1 root root   32 Nov  7 15:27 vcan.service -> /lib/systemd/system/vcan.service
```

Reboot and verify. `sudo shutdown -r now`
```
debian@beaglebone:~$ ifconfig

vcan0: flags=193<UP,RUNNING,NOARP>  mtu 72
        unspec 00-00-00-00-00-00-00-00-00-00-00-00-00-00-00-00  txqueuelen 1000  (UNSPEC)
        RX packets 0  bytes 0 (0.0 B)
        RX errors 0  dropped 0  overruns 0  frame 0
        TX packets 0  bytes 0 (0.0 B)
        TX errors 0  dropped 0 overruns 0  carrier 0  collisions 0

vcan1: flags=193<UP,RUNNING,NOARP>  mtu 72
        unspec 00-00-00-00-00-00-00-00-00-00-00-00-00-00-00-00  txqueuelen 1000  (UNSPEC)
        RX packets 0  bytes 0 (0.0 B)
        RX errors 0  dropped 0  overruns 0  frame 0
        TX packets 0  bytes 0 (0.0 B)
        TX errors 0  dropped 0 overruns 0  carrier 0  collisions 0

vcan2: flags=193<UP,RUNNING,NOARP>  mtu 72
        unspec 00-00-00-00-00-00-00-00-00-00-00-00-00-00-00-00  txqueuelen 1000  (UNSPEC)
        RX packets 0  bytes 0 (0.0 B)
        RX errors 0  dropped 0  overruns 0  frame 0
        TX packets 0  bytes 0 (0.0 B)
        TX errors 0  dropped 0 overruns 0  carrier 0  collisions 0
```

Now there are 3 vcan channels ready for use. 

### Add Software Packages
Run these commands to get the latest versions.
```
sudo apt update
sudo apt upgrade
```

Run these commands to get dependencies for the Beagle Bone Black. 

Install Jupyter so we can run Jupyter notebooks on the Beagle Bone Black
```
sudo pip3 install jupyter
```

You can launch a jupyter notebook server from the Beagle Bone:
```
jupyter notebook --ip 192.168.7.2 --no-browser
```

These dependencies are needed for the Jupyter live plotting examples.
```
sudo apt install libjpeg-dev -y
sudo apt install zlib1g-dev -y
sudo apt install libfreetype6-dev -y
sudo apt install zip -y
sudo apt install libopenjp2-7 -y
```

Also, install the cryptography library:
```
sudo pip3 install cryptography
```
This should report  `Successfully installed cryptography-3.2.1`

### Truck Cape Projects
Clone the Git Repository
```
cd ~
git clone https://github.com/SystemsCyber/TruckCapeProjects.git
```

## J1708 drivers

Install PyPRUSS for both Python 2.7 and 3.7
```
git clone https://bitbucket.org/intelligentagent/pypruss.git  
cd pypruss
sudo python setup.py install
sudo python3 setup.py install
#export LD_LIBRARY_PATH=/usr/local/lib
```

### hv_networks
Install the hv_networks drivers. First, clone the repository, then install the packages.
```
git clone https://github.com/SystemsCyber/py-hv-networks.git
cd py-hv-networks
sudo python3 setup.py install
```

Copy the PRU files to the OS:
```
sudo cp -r bbonePRU /opt/
```

Create an init script to load the PRU drivers.
```
sudo nano /etc/load_j1708_drivers.sh 
```

Add the following contents:
```
#!/bin/sh -e
/opt/bbonePRU/ecm_driver.py
/opt/bbonePRU/non_ecm_driver.py
exit 0
```

Make the script executable:
```
sudo chmod +x /etc/load_j1708_drivers.sh 
```

Write a service to run this script on boot.
```
sudo nano /lib/systemd/system/ecm_driver.service
```
Add this to the file:
```
[Unit]
Description=Load Python Drivers to Load J1708 PRU code

[Service]
Type=simple
Restart=on-failure
RestartSec=3
ExecStart=/opt/bbonePRU/ecm_driver.py

[Install]
WantedBy=multi-user.target
```

It's important to include the restart features because the first time the script is run, it usually fails. The script gets invoked before all the PRU infrastructure is loaded. 

Test the service:
```
sudo systemctl start ecm_driver.service
```

Enable the service at boot:
```
sudo systemctl enable ecm_driver.service
```

Verify the ecm_drivers loaded:
```
sudo systemctl status ecm_driver.service
```

Repeat the a creation of the same service, but substitute `non_ecm_driver` for `ecm_driver`.

Reboot and see if things worked: `sudo shutdown -r now`

After rebooting, you can check the status of the service:
```
debian@beaglebone:~$ sudo systemctl status ecm_driver.service
● ecm_driver.service - Load Python Drivers to Load J1708 PRU code
   Loaded: loaded (/lib/systemd/system/ecm_driver.service; enabled; vendor preset: enabled)
   Active: active (running) since Sat 2020-11-14 21:27:36 UTC; 36s ago
 Main PID: 2420 (python2.7)
    Tasks: 3 (limit: 1026)
   Memory: 2.7M
   CGroup: /system.slice/ecm_driver.service
           └─2420 python2.7 /opt/bbonePRU/ecm_driver.py

Nov 14 21:27:36 beaglebone systemd[1]: Started Load Python Drivers to Load J1708 PRU code.
Nov 14 21:27:37 beaglebone ecm_driver.py[2420]: AM33XX
Nov 14 21:27:37 beaglebone ecm_driver.py[2420]: File /opt/bbonePRU/text1.bin open passed
```

For more on the PRU: https://github.com/nesl/Cyclops-PRU

## Write a recovery SD card
With the heavy vehicle specific software installed, we can 
To duplicate the firmware image on the eMMC of the current Beagle Bone Black, do the following:
1. Remove the BBBlack from the truck cape. Power up with USB. 
1. Insert a blank SD card 4GB or bigger as soon as the user LEDs flash on boot. This timing seems to help ensure the SD card is recognized by the kernel. Plugging in the SD card later may not work. This is a physical hack to ensure the SD card can work.
1. Connect the Ethernet to a live Internet connection.
2. Login 
1. Update the scripts
```
cd /opt/scripts
git pull
```
2. Run the command 
```
sudo /opt/scripts/tools/eMMC/beaglebone-black-make-microSD-flasher-from-eMMC.sh 
```
3. Wait for the program to finish.
```
================================================================================
eMMC has been flashed: please wait for device to power down.
================================================================================
Calling shutdown
```
4. Eject the card. It is ready to use.

If the process fails, double check the SD card insertion and timing. 

## Future Work
This section documents some experimentation for upgrading the kernel and working with the J1939 SocketCAN extension. None of the examples or exercises use this section. In fact, none of the examples in this repository have been verified to work with this upgrade. 

### Upgrade the Linux Kernel Module for SocketCAN

First, we must upgrade the kernel version on the beaglebone. This step requires a connection between the beaglebone and the Internet.
From: https://elinux.org/Beagleboard:BeagleBoneBlack_Debian#Kernel_Upgrade

```
debian@beaglebone:~$ cd /opt/scripts/tools/
debian@beaglebone:~$ git pull
debian@beaglebone:~$ sudo ./update_kernel.sh --lts-5_4
debian@beaglebone:~$ sudo reboot
```

As of October 7, 2020, this updates to beaglebone kernel 5.4.66-ti-r18.

Next, we need the files for the can-j1939 kernel module. These may be found in the kernel_modules directory of the repository. If the TruckCapeProjects repository is not downloaded, you may download it with the following commands:
```
debian@beaglebone:~$ sudo git clone https://github.com/SystemsCyber/TruckCapeProjects.git
```
We also need to install the linux headers to build modules natively on the beaglebone.

```
debian@beaglebone:~$ sudo apt install linux-headers-`uname -r`

```

Once installed, navigate to the "j1939" directory and compile the kernel module using the "make" command.
```
debian@beaglebone:~$ cd ~/TruckCapeProjects/kernel_modules/j1939
```
Now we need to compile the kernel module.
```
debian@beaglebone:~/TruckCapeProjects/kernel_modules/j1939$ sudo make
```
After making the can-j1939 module, we need to put it into the correct folder.

```
debian@beaglebone:~/TruckCapeProjects/kernel_modules/j1939$ sudo mkdir /lib/modules/5.4.66-ti-r18/kernel/net/can/j1939
debian@beaglebone:~/TruckCapeProjects/kernel_modules/j1939$ sudo cp can-j1939.ko /lib/modules/5.4.66-ti-r18/kernel/net/can/j1939
```

```
debian@beaglebone:~$ sudo depmod
debian@beaglebone:~$ sudo modprobe can-j1939
```
The beaglebone kernel has now been upgraded and includes the j1939 module for SocketCAN.

As a final step, we need to install the correct Linux Header Files for local code compilation.

```
debian@beaglebone:~$ sudo apt-get install linux-headers-`uname -r`
debian@beaglebone:~$ sudo cp -r ~/TruckCapeProjects/header_files/include /usr/
```

The beaglebone kernel is now upgraded to 5.4.x and has the capability to both run and compile code which uses the can-j1939 kernel module.

### Socket-CAN and can-utils
Get the latest version of can-utils that supports J1939. Download the package using curl:

```
debian@beaglebone:~$ curl http://http.us.debian.org/debian/pool/main/c/can-utils/can-utils_2020.02.04-3_armhf.deb --output can-utils_2020.02.04-3_armhf.deb
```

Install the package using dpkg

```
debian@beaglebone:~$ sudo dpkg  -i can-utils_2020.02.04-3_armhf.deb
(Reading database ... 72570 files and directories currently installed.)
Preparing to unpack can-utils_2020.02.04-3_armhf.deb ...
Unpacking can-utils (2020.02.04-3) over (2018.02.0-1) ...
Setting up can-utils (2020.02.04-3) ...
Processing triggers for man-db (2.8.5-2) ...
```

https://github.com/linux-can/can-utils

This might be interesting: https://www.beyondlogic.org/example-c-socketcan-code/

### Python and CAN
https://www.thomas-wedemeyer.de/beaglebone-canbus-python.html

python-can

https://justkding.me/thoughts/python-sae-j1939-socket-support

## J1708 drivers
Follow the instructions at https://github.com/TruckHacking/plc4trucksduck 

Write a J1708 socket driver.

## Other Resources
https://www.element14.com/community/community/designcenter/single-board-computers/next-genbeaglebone/blog/2019/08/15/beaglebone-black-bbb-io-gpio-spi-and-i2c-library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

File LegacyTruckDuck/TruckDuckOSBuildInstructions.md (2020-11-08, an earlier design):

# Original TruckDuck Build Instructions

More specifically, the image will have the following:

1. ARM Linux Kernel 3. 
  
   ```uname -a```
  
   ```Linux truck-duck 3.8.13+ #3 SMP Fri Jul 1 14:46:43 CDT 2016 armv7l armv7l armv7l GNU/Linux```
  
2. J1939 Kernel Extension
3. can-utils
4. py-hv-drivers
5. Python 3.5.2

Default Credentials
U: ubuntu P: truckduck
Please change the password if this is connected to the Internet.

An ASCII art image of a duck should appear.

## Installing the TruckDuck or TruckCape Distribution
The compressed sd card image is linked here: https://www.dropbox.com/s/j8maeqj8ru7p7ck/truck-duck-18sept2016.7z?dl=0

Reference Website: https://truckhacking.github.io/

## Converting the Truck Cape into a Datalogger
To make a logger, you can automatically start candump.

Add the following to the /etc/init/truckduck/truckduck.conf file at the end:

```#set up to automatically log on boot.
cd /home/ubuntu
candump -l any &
end script

```
The dated data files will be available in the home directory. You will have to log in to

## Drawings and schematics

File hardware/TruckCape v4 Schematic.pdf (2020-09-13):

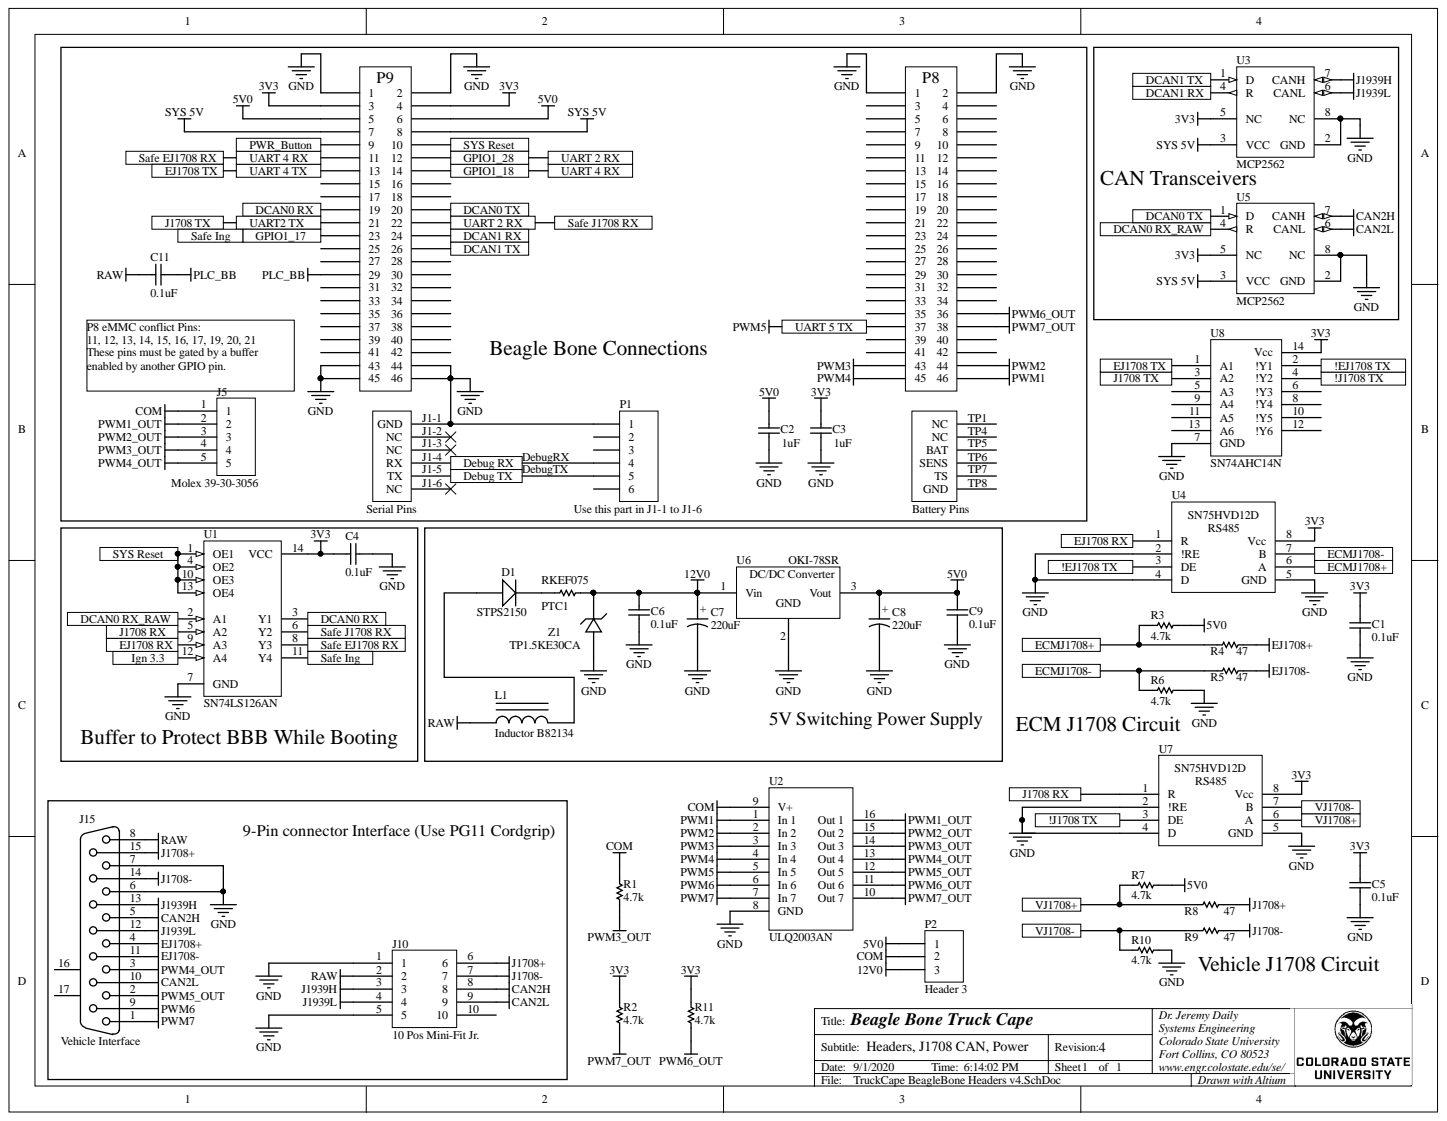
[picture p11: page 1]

P8 eMMC conflict Pins:
These pins must be gated by a buffer
enabled by another GPIO pin.

Use this part in J1-1 to J1-6

Buffer to Protect BBB While Booting

9-Pin connector Interface (Use PG11 Cordgrip)

14

Beagle Bone Truck Cape
Title:

10 Pos Mini-Fit Jr.

Subtitle:
TruckCape BeagleBone Headers v4.SchDoc

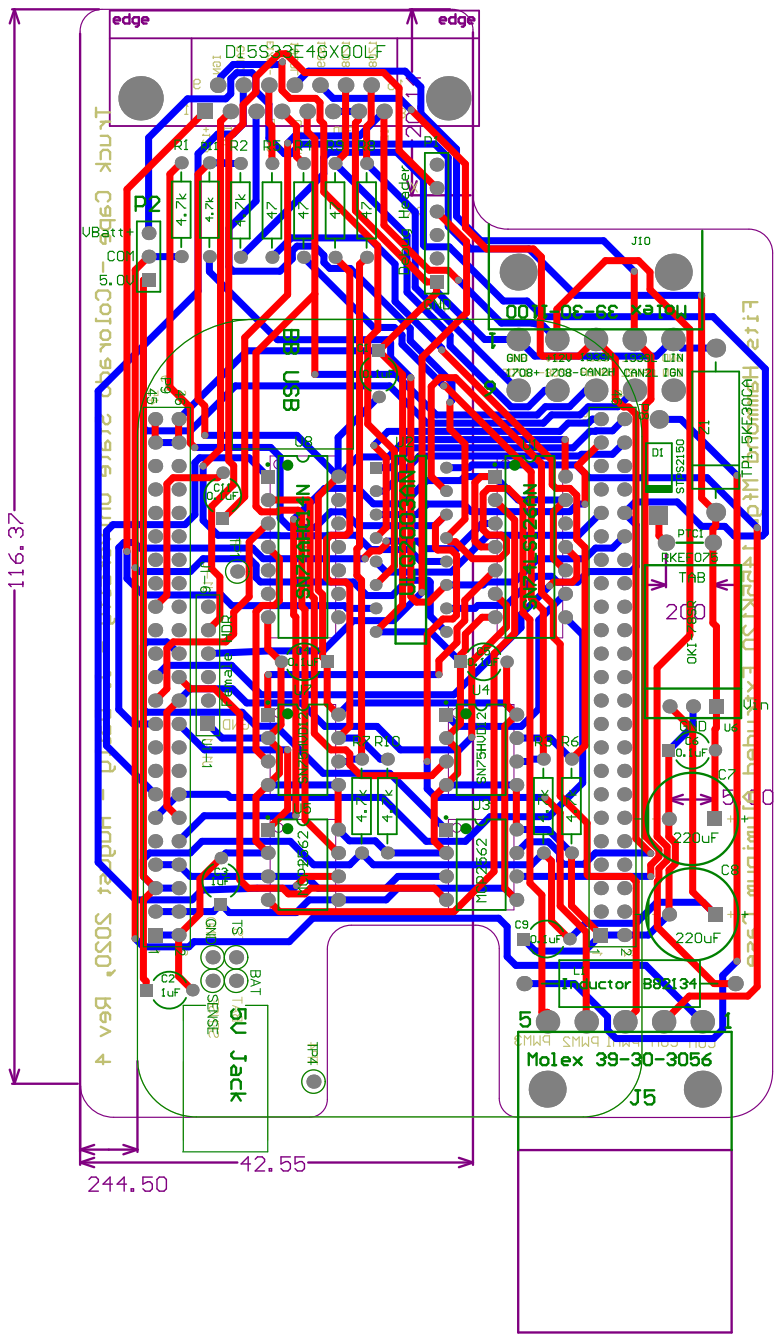
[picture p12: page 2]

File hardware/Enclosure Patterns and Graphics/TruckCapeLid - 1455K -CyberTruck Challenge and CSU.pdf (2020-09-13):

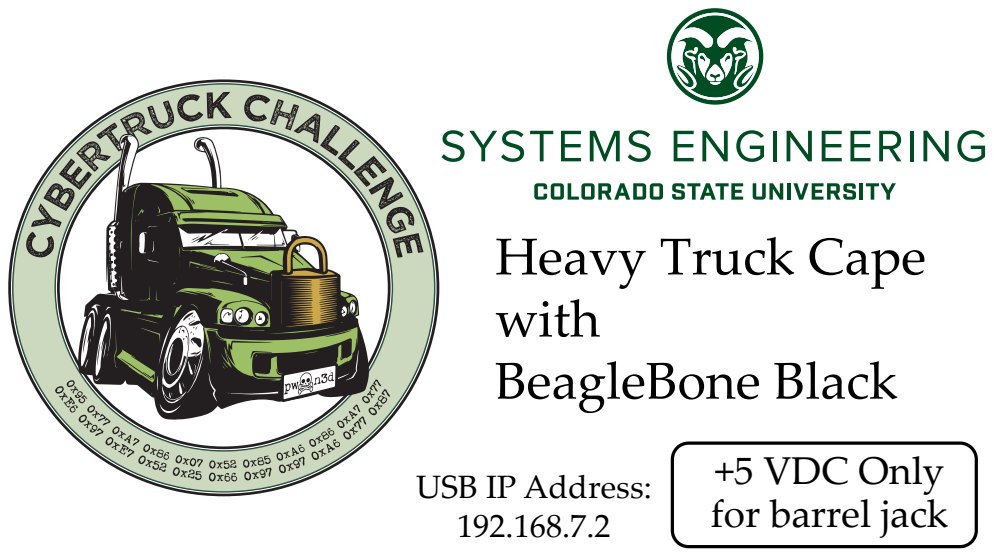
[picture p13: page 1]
+5 VDC Only

Heavy Truck Cape
with
BeagleBone Black

for barrel jack USB IP Address:

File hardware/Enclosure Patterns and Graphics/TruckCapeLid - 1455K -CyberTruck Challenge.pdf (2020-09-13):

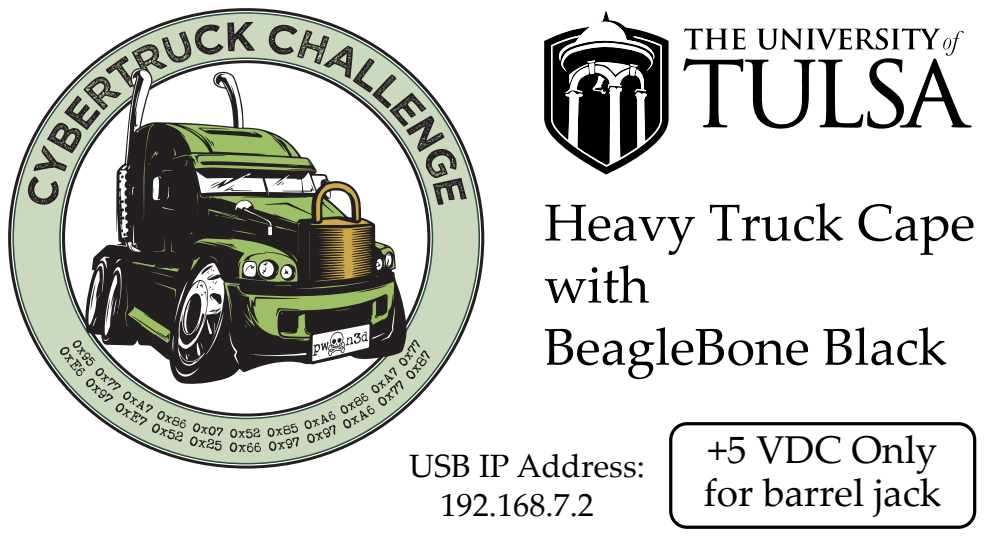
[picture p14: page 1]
+5 VDC Only

Heavy Truck Cape
with
BeagleBone Black

for barrel jack USB IP Address:

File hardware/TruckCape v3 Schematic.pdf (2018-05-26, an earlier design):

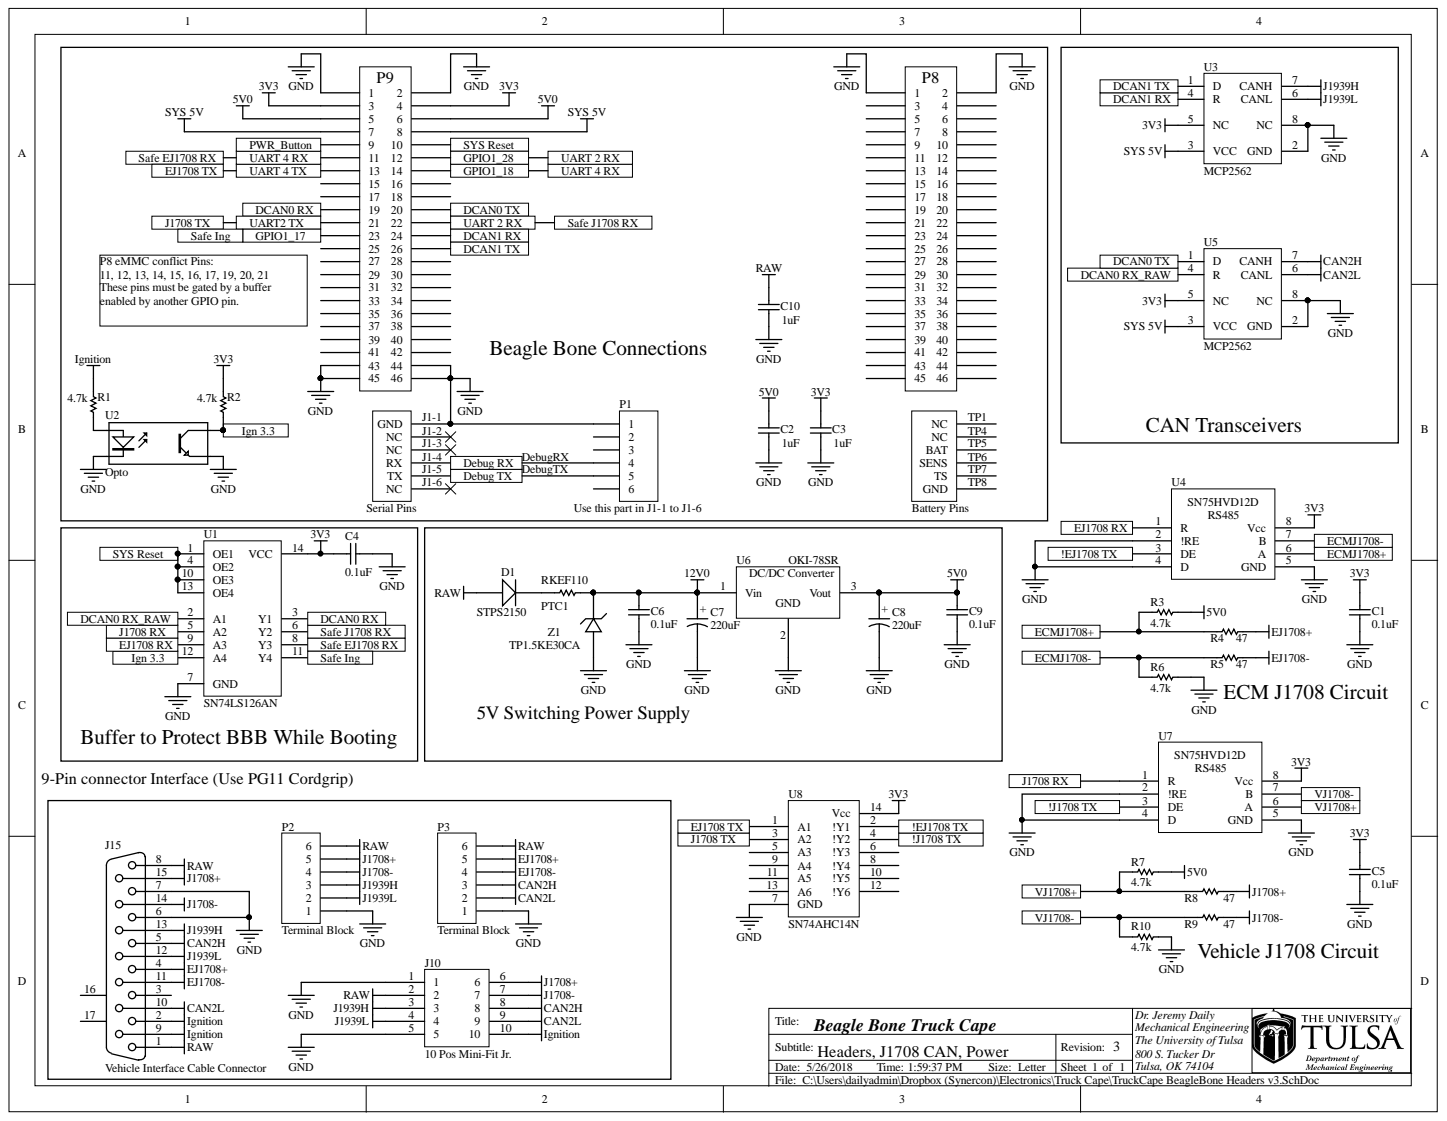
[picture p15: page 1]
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

Use this part in J1-1 to J1-6

Buffer to Protect BBB While Booting

9-Pin connector Interface (Use PG11 Cordgrip)

Title:
Beagle Bone Truck Cape

Dr. Jeremy Daily
Mechanical Engineering
The University of Tulsa
800 S. Tucker Dr
Tulsa, OK 74104

Subtitle:
C:\Users\dailyadmin\Dropbox (Synercon)\Electronics\Truck Cape\TruckCape BeagleBone Headers v3.SchDoc

10 Pos Mini-Fit Jr.

Vehicle Interface Cable Connector

Item # | Manufacturer | #Column Name Error:Manufacturer No | Quantity | #Column Name Error:Note | Designator | Description | Footprint | Comment | LibRef
1 | Sullins Connector Solutions | | 1 | | BeagleBoneBlack1 | 46 Positions Header, Breakaway Connector 0.100" (2.54mm) Through Hole Tin | Beagleboneblack | BeagleBoneBlack | BeagleBoneBlack
2 | Vishay BC Components | | 5 | | C1, C4, C5, C6, C9 | CAP CER 0.1UF 100V X7R RADIAL | CAPR5-4X5 | 0.1uF | Cap
3 | Murata Electronics North America | | 3 | | C2, C3, C10 | CAP CER 1UF 100V X7R RADIAL | CAPR5-4X5 | 1uF | Cap
4 | EPCOS (TDK) | | 2 | | C7, C8 | 220µF 50V Aluminum Electrolytic Capacitors Radial, Can 175 mOhm @ 10kHz 5000 Hrs @ 105°C | Elec. Cap 5 x 10mm | 220uF | Electrolytic Cap
5 | STMicroelectronics | | 1 | | D1 | Diode Schottky 150V 2A Through Hole DO-15 | DO-41 | STPS2150 | Diode 1N4003
6 | Molex | | 1 | | J10 | 10 Positions Header Connector 0.165" (4.20mm) Through Hole, Right Angle Tin | 10 pos Mini-Fit Jr. R/A Header | 10 Pos Mini-Fit Jr. | 10 Pos Header
7 | Amphenol FCI | | 1 | | J15 | Receptacle Assembly, 15 Position, Right Angle, 8.08mm Series, Amplimite, with Screwlocks | DB15 | Vehicle Interface Cable Connector | 788781-2
8 | Sullins Connector Solutions | | 1 | | P1 | CONN HEADER FEMALE 6POS .1" GOLD | HDR1X6 | Use this part in J1-1 to J1-6 | Header 6
9 | TE Connectivity AMP Connectors | | 2 | | P2, P3 | 6 Position Wire to Board Terminal Block Horizontal with Board 0.100" (2.54mm) Through Hole | HDR1X6 | Terminal Block | Header 6
10 | Littelfuse Inc. | | 1 | | PTC1 | Polymeric PTC Resettable Fuse 60V 1.1A Ih Through Hole Radial, Disc | PTC | RKEF110 | SMD Resistor
11 | Yageo | | 6 | | R1, R2, R3, R6, R7, R10 | RES SMD 4.7K OHM 1% 1/10W 0603 | Axial-0.4 | 4.7k | Chip Resistor
12 | Yageo | | 4 | | R4, R5, R8, R9 | 47 Ohms ±5% 0.25W, 1/4W Through Hole Resistor Axial Carbon Film | Axial-0.4 | 47 | Chip Resistor
13 | Texas Instruments | | 1 | | U1 | Quad 3-State Buffer | N14A | SN74LS126AN | DM74LS126AN
14 | | | 1 | | U2 | 4-Pin Phototransistor Optocoupler | DIP-4 | Opto | Optoisolator1
15 | Microchip Technology | | 2 | | U3, U5 | 1/1 Transceiver Half CAN 8-PDIP | PDIP300-P8 | MCP2562 | SN65HVD232DR
16 | Texas Instruments | | 2 | | U4, U7 | IC 3.3V DIFF TXRX 8-SOIC | PDIP300-P8 | SN75HVD12 | SN75HVD12D (3.3v RS485)
17 | Murata Power Solutions Inc. | | 1 | | U6 | 5V DC/DC Converter (7805 replacement) | OKI-78SR | OKI-78SR | 7805
18 | Texas Instruments | | 1 | | U8 | Inverter IC 6 Channel Schmitt Trigger 14-PDIP | N14A | SN74AHC14N | 74VHC14 Hex Inverter
19 | Littelfuse Inc. | | 1 | | Z1 | TVS DIODE 25.6V 41.4V DO201 | DIODE-0.7 | TP1.5KE30CA | Zener

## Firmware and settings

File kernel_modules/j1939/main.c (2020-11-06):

// SPDX-License-Identifier: GPL-2.0
// Copyright (c) 2010-2011 EIA Electronics,
//                         Pieter Beyens <pieter.beyens@eia.be>
// Copyright (c) 2010-2011 EIA Electronics,
//                         Kurt Van Dijck <kurt.van.dijck@eia.be>
// Copyright (c) 2018 Protonic,
//                         Robin van der Gracht <robin@protonic.nl>
// Copyright (c) 2017-2019 Pengutronix,
//                         Marc Kleine-Budde <kernel@pengutronix.de>
// Copyright (c) 2017-2019 Pengutronix,
//                         Oleksij Rempel <kernel@pengutronix.de>

/* Core of can-j1939 that links j1939 to CAN. */

#include <linux/can/can-ml.h>
#include <linux/can/core.h>
#include <linux/can/skb.h>
#include <linux/if_arp.h>
#include <linux/module.h>

#include "j1939-priv.h"

MODULE_DESCRIPTION("PF_CAN SAE J1939");
MODULE_LICENSE("GPL v2");
MODULE_AUTHOR("EIA Electronics (Kurt Van Dijck & Pieter Beyens)");
MODULE_ALIAS("can-proto-" __stringify(CAN_J1939));

/* LOWLEVEL CAN interface */

/* CAN_HDR: #bytes before can_frame data part */
#define J1939_CAN_HDR (offsetof(struct can_frame, data))

/* CAN_FTR: #bytes beyond data part */
#define J1939_CAN_FTR (sizeof(struct can_frame) - J1939_CAN_HDR - \
		 sizeof(((struct can_frame *)0)->data))

/* lowest layer */
static void j1939_can_recv(struct sk_buff *iskb, void *data)
{
	struct j1939_priv *priv = data;
	struct sk_buff *skb;
	struct j1939_sk_buff_cb *skcb, *iskcb;
	struct can_frame *cf;

	/* create a copy of the skb
	 * j1939 only delivers the real data bytes,
	 * the header goes into sockaddr.
	 * j1939 may not touch the incoming skb in such way
	 */
	skb = skb_clone(iskb, GFP_ATOMIC);
	if (!skb)
		return;

	j1939_priv_get(priv);
	can_skb_set_owner(skb, iskb->sk);

	/* get a pointer to the header of the skb
	 * the skb payload (pointer) is moved, so that the next skb_data
	 * returns the actual payload
	 */
	cf = (void *)skb->data;
	skb_pull(skb, J1939_CAN_HDR);

	/* fix length, set to dlc, with 8 maximum */
	skb_trim(skb, min_t(uint8_t, cf->can_dlc, 8));

	/* set addr */
	skcb = j1939_skb_to_cb(skb);
	memset(skcb, 0, sizeof(*skcb));

	iskcb = j1939_skb_to_cb(iskb);
	skcb->tskey = iskcb->tskey;
	skcb->priority = (cf->can_id >> 26) & 0x7;
	skcb->addr.sa = cf->can_id;
	skcb->addr.pgn = (cf->can_id >> 8) & J1939_PGN_MAX;
	/* set default message type */
	skcb->addr.type = J1939_TP;
	if (j1939_pgn_is_pdu1(skcb->addr.pgn)) {
		/* Type 1: with destination address */
		skcb->addr.da = skcb->addr.pgn;
		/* normalize pgn: strip dst address */
		skcb->addr.pgn &= 0x3ff00;
	} else {
		/* set broadcast address */
		skcb->addr.da = J1939_NO_ADDR;
	}

	/* update localflags */
	read_lock_bh(&priv->lock);
	if (j1939_address_is_unicast(skcb->addr.sa) &&
	    priv->ents[skcb->addr.sa].nusers)
		skcb->flags |= J1939_ECU_LOCAL_SRC;
	if (j1939_address_is_unicast(skcb->addr.da) &&
	    priv->ents[skcb->addr.da].nusers)
		skcb->flags |= J1939_ECU_LOCAL_DST;
	read_unlock_bh(&priv->lock);

	/* deliver into the j1939 stack ... */
	j1939_ac_recv(priv, skb);

	if (j1939_tp_recv(priv, skb))
		/* this means the transport layer processed the message */
		goto done;

	j1939_simple_recv(priv, skb);
	j1939_sk_recv(priv, skb);
 done:
	j1939_priv_put(priv);
	kfree_skb(skb);
}

/* NETDEV MANAGEMENT */

/* values for can_rx_(un)register */
#define J1939_CAN_ID CAN_EFF_FLAG
#define J1939_CAN_MASK (CAN_EFF_FLAG | CAN_RTR_FLAG)

static DEFINE_SPINLOCK(j1939_netdev_lock);

static struct j1939_priv *j1939_priv_create(struct net_device *ndev)
{
	struct j1939_priv *priv;

	priv = kzalloc(sizeof(*priv), GFP_KERNEL);
	if (!priv)
		return NULL;

	rwlock_init(&priv->lock);
	INIT_LIST_HEAD(&priv->ecus);
	priv->ndev = ndev;
	kref_init(&priv->kref);
	kref_init(&priv->rx_kref);
	dev_hold(ndev);

	netdev_dbg(priv->ndev, "%s : 0x%p\n", __func__, priv);

	return priv;
}

static inline void j1939_priv_set(struct net_device *ndev,
				  struct j1939_priv *priv)
{
	struct can_ml_priv *can_ml_priv = ndev->ml_priv;

	can_ml_priv->j1939_priv = priv;
}

static void __j1939_priv_release(struct kref *kref)
{
	struct j1939_priv *priv = container_of(kref, struct j1939_priv, kref);
	struct net_device *ndev = priv->ndev;

	netdev_dbg(priv->ndev, "%s: 0x%p\n", __func__, priv);

	WARN_ON_ONCE(!list_empty(&priv->active_session_list));
	WARN_ON_ONCE(!list_empty(&priv->ecus));
	WARN_ON_ONCE(!list_empty(&priv->j1939_socks));

	dev_put(ndev);
	kfree(priv);
}

void j1939_priv_put(struct j1939_priv *priv)
{
	kref_put(&priv->kref, __j1939_priv_release);
}

void j1939_priv_get(struct j1939_priv *priv)
{
	kref_get(&priv->kref);
}

static int j1939_can_rx_register(struct j1939_priv *priv)
{
	struct net_device *ndev = priv->ndev;
	int ret;

	j1939_priv_get(priv);
	ret = can_rx_register(dev_net(ndev), ndev, J1939_CAN_ID, J1939_CAN_MASK,
			      j1939_can_recv, priv, "j1939", NULL);
	if (ret < 0) {
		j1939_priv_put(priv);
		return ret;
	}

	return 0;
}

static void j1939_can_rx_unregister(struct j1939_priv *priv)
{
	struct net_device *ndev = priv->ndev;

	can_rx_unregister(dev_net(ndev), ndev, J1939_CAN_ID, J1939_CAN_MASK,
			  j1939_can_recv, priv);

	j1939_priv_put(priv);
}

static void __j1939_rx_release(struct kref *kref)
	__releases(&j1939_netdev_lock)
{
	struct j1939_priv *priv = container_of(kref, struct j1939_priv,
					       rx_kref);

	j1939_can_rx_unregister(priv);
	j1939_ecu_unmap_all(priv);
	j1939_priv_set(priv->ndev, NULL);
	spin_unlock(&j1939_netdev_lock);
}

/* get pointer to priv without increasing ref counter */
static inline struct j1939_priv *j1939_ndev_to_priv(struct net_device *ndev)
{
	struct can_ml_priv *can_ml_priv = ndev->ml_priv;

	if (!can_ml_priv)
		return NULL;

	return can_ml_priv->j1939_priv;
}

static struct j1939_priv *j1939_priv_get_by_ndev_locked(struct net_device *ndev)
{
	struct j1939_priv *priv;

	lockdep_assert_held(&j1939_netdev_lock);

	if (ndev->type != ARPHRD_CAN)
		return NULL;

	priv = j1939_ndev_to_priv(ndev);
	if (priv)
		j1939_priv_get(priv);

	return priv;
}

static struct j1939_priv *j1939_priv_get_by_ndev(struct net_device *ndev)
{
	struct j1939_priv *priv;

	spin_lock(&j1939_netdev_lock);
	priv = j1939_priv_get_by_ndev_locked(ndev);
	spin_unlock(&j1939_netdev_lock);

	return priv;
}

struct j1939_priv *j1939_netdev_start(struct net_device *ndev)
{
	struct j1939_priv *priv, *priv_new;
	int ret;

	priv = j1939_priv_get_by_ndev(ndev);
	if (priv) {
		kref_get(&priv->rx_kref);
		return priv;
	}

	priv = j1939_priv_create(ndev);
	if (!priv)
		return ERR_PTR(-ENOMEM);

	j1939_tp_init(priv);
	spin_lock_init(&priv->j1939_socks_lock);
	INIT_LIST_HEAD(&priv->j1939_socks);

	spin_lock(&j1939_netdev_lock);
	priv_new = j1939_priv_get_by_ndev_locked(ndev);
	if (priv_new) {
		/* Someone was faster than us, use their priv and roll
		 * back our's.
		 */
		spin_unlock(&j1939_netdev_lock);
		dev_put(ndev);
		kfree(priv);
		kref_get(&priv_new->rx_kref);
		return priv_new;
	}
	j1939_priv_set(ndev, priv);
	spin_unlock(&j1939_netdev_lock);

	ret = j1939_can_rx_register(priv);
	if (ret < 0)
		goto out_priv_put;

	return priv;

 out_priv_put:
	j1939_priv_set(ndev, NULL);
	dev_put(ndev);
	kfree(priv);

	return ERR_PTR(ret);
}

void j1939_netdev_stop(struct j1939_priv *priv)
{
	kref_put_lock(&priv->rx_kref, __j1939_rx_release, &j1939_netdev_lock);
	j1939_priv_put(priv);
}

int j1939_send_one(struct j1939_priv *priv, struct sk_buff *skb)
{
	int ret, dlc;
	canid_t canid;
	struct j1939_sk_buff_cb *skcb = j1939_skb_to_cb(skb);
	struct can_frame *cf;

	/* apply sanity checks */
	if (j1939_pgn_is_pdu1(skcb->addr.pgn))
		skcb->addr.pgn &= J1939_PGN_PDU1_MAX;
	else
		skcb->addr.pgn &= J1939_PGN_MAX;

	if (skcb->priority > 7)
		skcb->priority = 6;

	ret = j1939_ac_fixup(priv, skb);
	if (unlikely(ret))
		goto failed;
	dlc = skb->len;

	/* re-claim the CAN_HDR from the SKB */
	cf = skb_push(skb, J1939_CAN_HDR);

	/* make it a full can frame again */
	skb_put(skb, J1939_CAN_FTR + (8 - dlc));

	canid = CAN_EFF_FLAG |
		(skcb->priority << 26) |
		(skcb->addr.pgn << 8) |
		skcb->addr.sa;
	if (j1939_pgn_is_pdu1(skcb->addr.pgn))
		canid |= skcb->addr.da << 8;

	cf->can_id = canid;
	cf->can_dlc = dlc;

	return can_send(skb, 1);

 failed:
	kfree_skb(skb);
	return ret;
}

static int j1939_netdev_notify(struct notifier_block *nb,
			       unsigned long msg, void *data)
{
	struct net_device *ndev = netdev_notifier_info_to_dev(data);
	struct j1939_priv *priv;

	priv = j1939_priv_get_by_ndev(ndev);
	if (!priv)
		goto notify_done;

	if (ndev->type != ARPHRD_CAN)
		goto notify_put;

	switch (msg) {
	case NETDEV_DOWN:
		j1939_cancel_active_session(priv, NULL);
		j1939_sk_netdev_event_netdown(priv);
		j1939_ecu_unmap_all(priv);
		break;
	}

notify_put:
	j1939_priv_put(priv);

notify_done:
	return NOTIFY_DONE;
}

static struct notifier_block j1939_netdev_notifier = {
	.notifier_call = j1939_netdev_notify,
};

/* MODULE interface */
static __init int j1939_module_init(void)
{
	int ret;

	pr_info("can: SAE J1939\n");

	ret = register_netdevice_notifier(&j1939_netdev_notifier);
	if (ret)
		goto fail_notifier;

	ret = can_proto_register(&j1939_can_proto);
	if (ret < 0) {
		pr_err("can: registration of j1939 protocol failed\n");
		goto fail_sk;
	}

	return 0;

 fail_sk:
	unregister_netdevice_notifier(&j1939_netdev_notifier);
 fail_notifier:
	return ret;
}

static __exit void j1939_module_exit(void)
{
	can_proto_unregister(&j1939_can_proto);

	unregister_netdevice_notifier(&j1939_netdev_notifier);
}

module_init(j1939_module_init);
module_exit(j1939_module_exit);

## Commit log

2017-05-25 Added TruckCape Schematics
    Need to connect pin 8 to ground if using an MCP2562
2018-05-26 added docs for verison 3
    [TruckCape BeagleBone Headers v3.SchDoc, TruckCape for Hammond 1455K - Rev3.PcbDoc, TruckCape v3 Bill of Materials.csv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]
2019-02-06 Create README.md
    Created tcpCANClient.py to collect data from a CAN interface and send it to a TCP Server. tcpCANServer.py listens for the client and formats the data of the CAN frames to the console similar to the f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
2019-02-06 Update tcpCANClient.py
    Change max CAN frames per TCP packet from 93 to 89 and max payload size from 1489 to 1425 to account for header fields of IP and TCP. Allows for up to 75 bytes for headers without fragmentation of me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
2019-02-06 Update tcpCANServer.py
    Removed dependencies on socketCAN so server need not be hosted on a Linux OS. Server now automatically sets the IP address to the machine's IP address.
2019-02-07 Update tcpCANServer.py
    Added logging to text file on server side as formated line for each CAN frame.
2019-02-12 Update readRawCANSocket.py
    Added socket options to enable socket to receive error frames.
2019-02-12 Update tcpCANClient.py
    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
2019-02-13 Update tcpCANClient.py
    Debugged. RTR, Error, Standard CAN, and Extended CAN frames are now able to be transmitted.
2019-02-28 Implemented txon/txoff commands for can0/can1/any
    Txon/txoff commands now turn on and off servers on different ports on the machine where tcpCANServer.py is found. These commands can now be used with can0/can1/any. An additional cangen command to tr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
2019-02-28 Updated CAN frame comments. Added command parsing on tcpCANServer.py.
    Updated the comments referring to structure of CAN frame. Also added logic for tcpCANServer.py to handle down, up, reset, and setbitrate logic. Functionality not yet implemented.
2019-02-28 Implemented busload command.
    The busload command now prints to the client the value of the estimated percentage busload gotten from using canbusload on the server side. Updated documentation and added format of percentage busloa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
2019-03-01 Implemented functionality of rxmsgs and txmsgs tcpCANServer.py commands.
    The rxmsgs and txmsgs now display the number of CAN messages received and transmitted over TCP. The results print on the server side and do not transfer the data to the client since it is mostly a fe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
2019-04-08 Laser cutter files for end pieces
2020-09-08 Setup for v4
    [TruckCape BeagleBone Headers v3.SchDoc, TruckCape BeagleBone Headers v4.SchDoc, TruckCape for Hammond 1455K - Rev3.PcbDoc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]
2020-09-09 slight adjustment for good fit of 5 pin molex
2020-09-21 Fix for non-booting bbone
    [TruckCape v4 Bill of Materials.csv]
2020-09-27 Added diagrams of cable assembly
2020-10-08 Typo fixes and J1939 Installation Guide
    [main.c]
2020-11-04 Change j1708 exercised to Socket CAN
2020-11-06 sample db
